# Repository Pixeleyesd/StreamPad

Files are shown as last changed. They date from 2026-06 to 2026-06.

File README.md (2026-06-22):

# StreamPad
The StreamPad is an open source hackpad made for macros (designed for streaming). It has 16 keys (4x4) and an OLED screen.

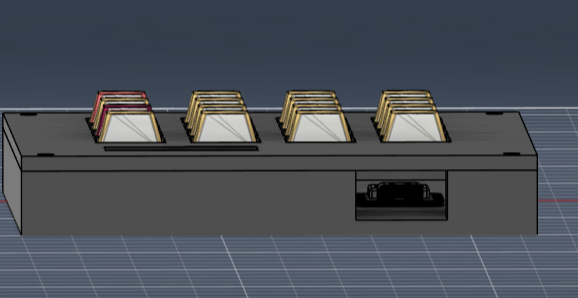
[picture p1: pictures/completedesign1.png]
design1

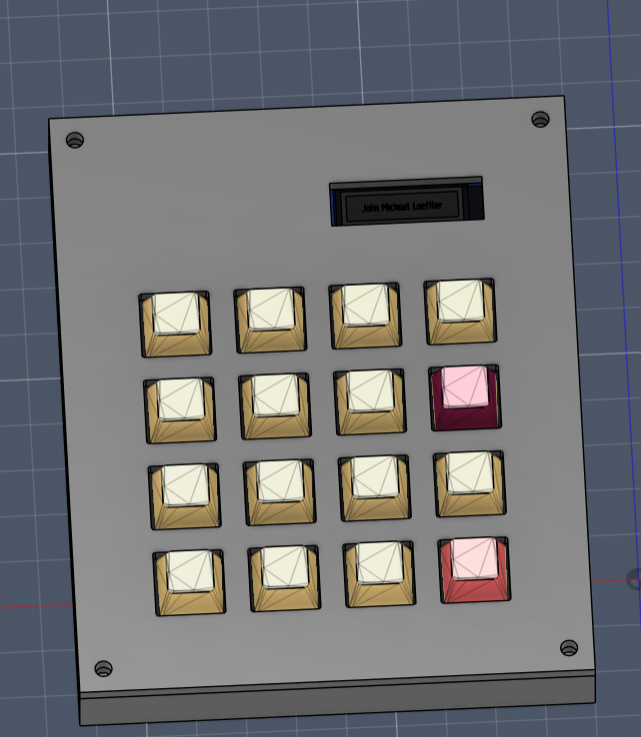
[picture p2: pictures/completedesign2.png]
design2


# PCB
Designed with KiCad.

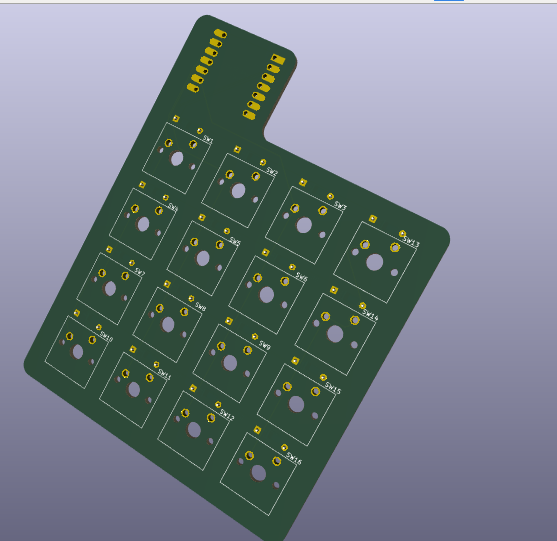
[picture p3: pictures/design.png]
design

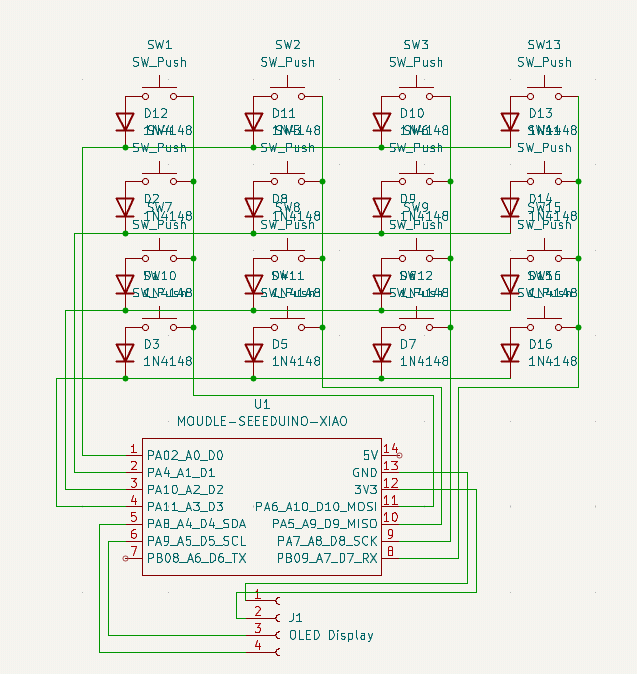
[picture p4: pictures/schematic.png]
schematic

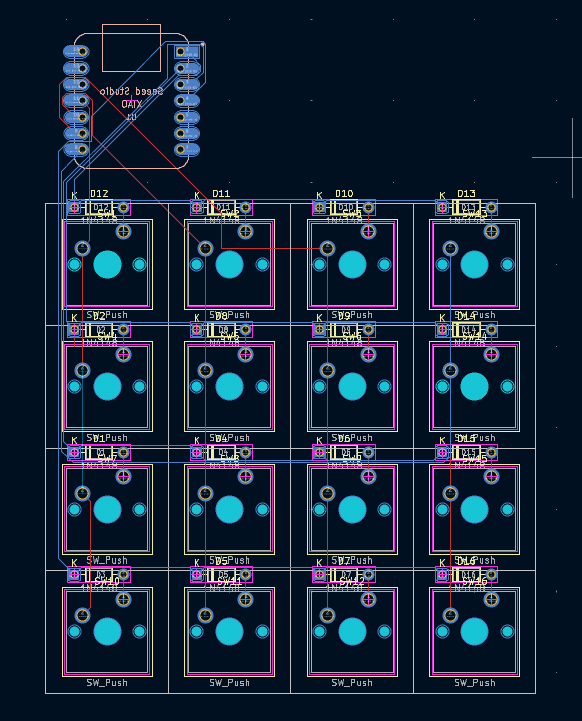
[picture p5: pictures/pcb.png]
pcb


# Case
Designed with fusion 360.

The macropad is assembled by pressing heat-set inserts into the back of the top plate. Then, 16mm screws are inserted through the bottom of the base and the PCB, threading directly into the inserts to hold everything together.

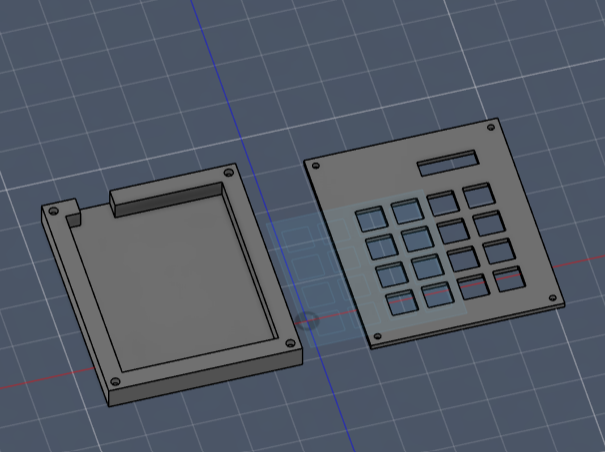
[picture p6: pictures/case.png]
case


# Firmware
The firmware is written in KMK.

You will need to flash the .uf2 provided in the Firmware folder in this repo to the Seeeduino XIAO. (Refer to help here: https://wiki.seeedstudio.com/XIAO-RP2040-with-CircuitPython/)

After this, drag the files in the circuitpy folder provided in this repo into the CIRCUITPY drive that shows up after flashing circuitpython to the microcontroller. Do this as you would a flash drive.

# Assemble
Bill Of Materials (BOM):

1x XIAO RP2040

16x Cherry MX Switches

16x DSA Keycaps

4x M3x5x4 Heatset inserts

4x M3x16mm screws

16x 1N4148 DO-35 Diodes

1x 0.91" 128x32 OLED Display

My 3D printed case (Top & Bottom)

My PCB design. (I'm planning to use JLCPCB for the custom assembly of it)

You will also need to solder wires from XIAO to OLED. The wires will be self-provided: 

GND -> GND

3v3 -> VCC

D4 -> SDA

D5 -> SCL

You will then need to attach the OLED onto the top half of the case.

---

This was my first time ever using KiCad for PCB design, and my first time properly shipping an open source project like this. I learned a lot about this sort of stuff with this project, and made many mistakes I will remember not to make again lol.
Thanks to the Hackclub (and Stardance) team for providing these amazing resources that helped make this dream of mine come true :3

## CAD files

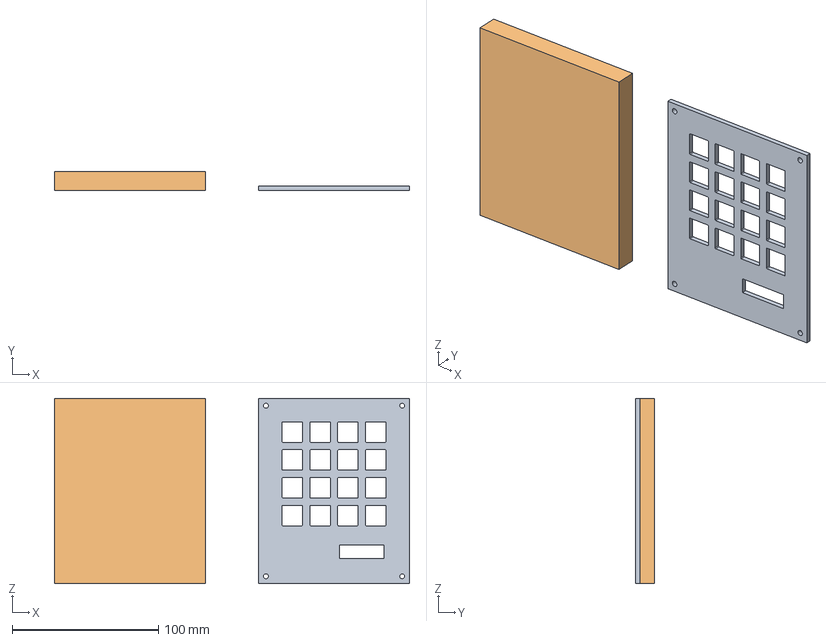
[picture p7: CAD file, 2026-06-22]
CAD/StreamPadCase.step
243.1 x 13.0 x 126.8 mm

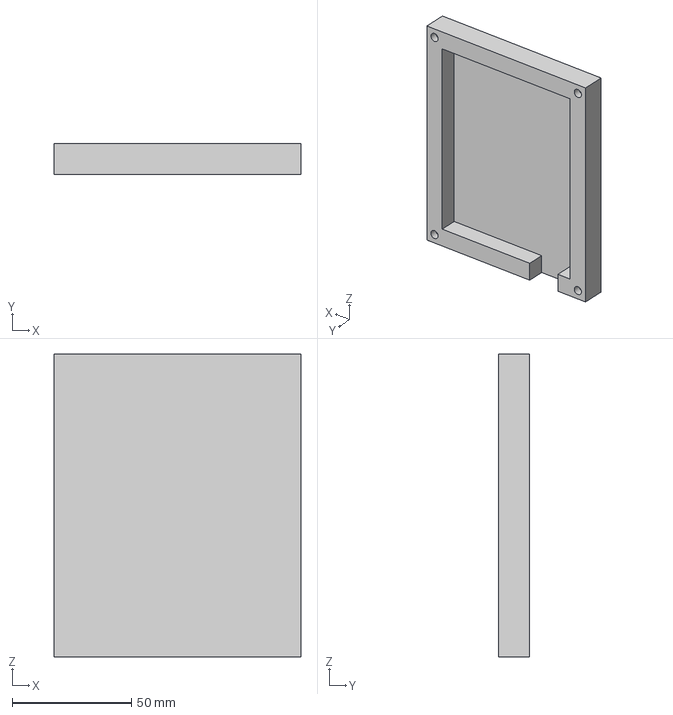
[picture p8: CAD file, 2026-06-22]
production/Bottom.step
103.4 x 13.0 x 126.8 mm

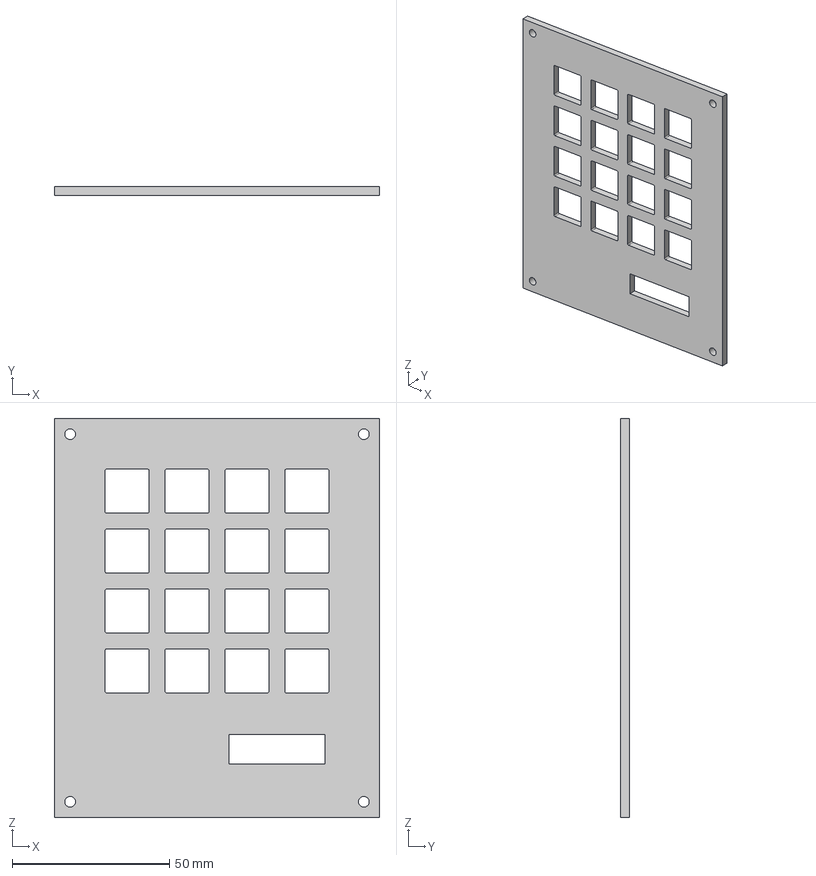
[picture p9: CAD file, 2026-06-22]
production/Top.step
103.4 x 3.00 x 126.8 mm

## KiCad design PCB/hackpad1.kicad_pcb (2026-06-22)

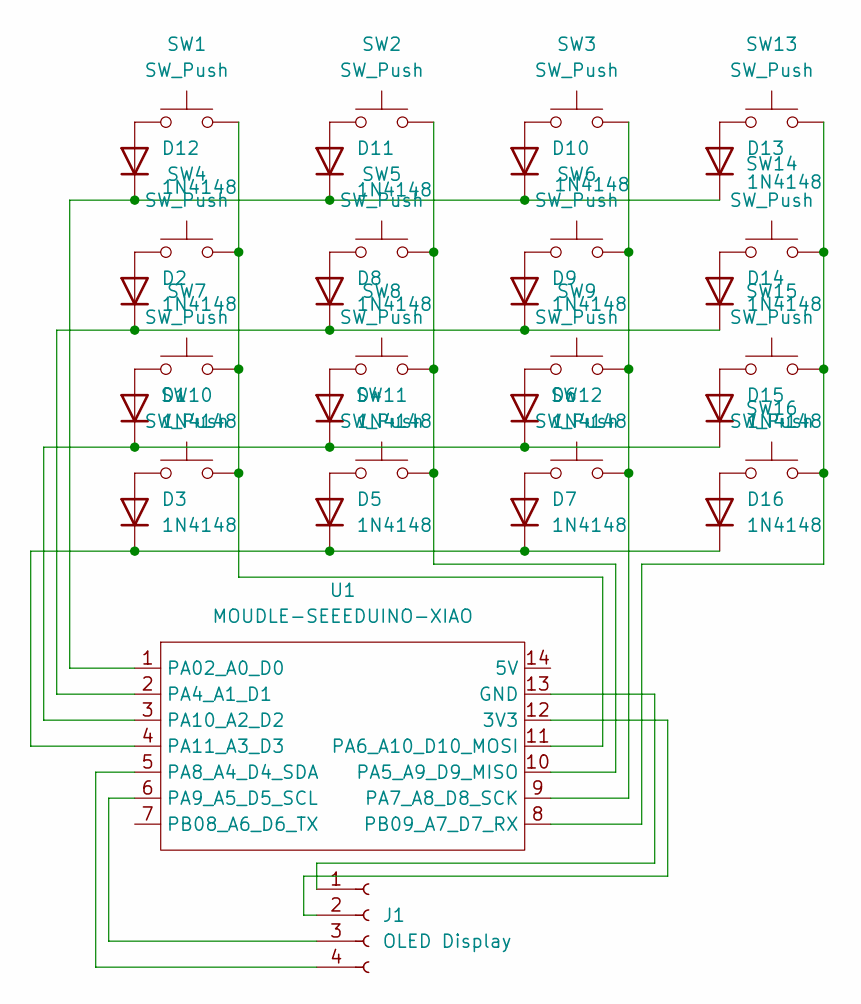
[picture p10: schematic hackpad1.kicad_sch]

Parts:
D1, D2, D3, D4, D5, D6, D7, D8, D9, D10, D11, D12, D13, D14, D15, D16: 1N4148; D_DO-35_SOD27_P7.62mm_Horizontal
J1: OLED Display
SW1, SW2, SW3, SW4, SW5, SW6, SW7, SW8, SW9, SW10, SW11, SW12, SW13, SW14, SW15, SW16: SW_Push; SW_Cherry_MX_1.00u_PCB
U1: MOUDLE-SEEEDUINO-XIAO; XIAO-Generic-Hybrid-14P-2.54-21X17.8MM

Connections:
unnamed: D1.2 (A), SW7.1
unnamed: D1.1 (K), D4.1 (K), D6.1 (K), D15.1 (K), U1.3 (PA10_A2_D2)
unnamed: D2.2 (A), SW4.1
unnamed: D3.2 (A), SW10.1
unnamed: D4.2 (A), SW8.1
unnamed: D5.2 (A), SW11.1
unnamed: D6.2 (A), SW9.1
unnamed: D7.2 (A), SW12.1
unnamed: D8.2 (A), SW5.1
unnamed: D9.2 (A), SW6.1
unnamed: D10.2 (A), SW3.1
unnamed: D10.1 (K), D11.1 (K), D12.1 (K), D13.1 (K), U1.1 (PA02_A0_D0)
unnamed: D11.2 (A), SW2.1
unnamed: D12.2 (A), SW1.1
unnamed: D13.2 (A), SW13.1
unnamed: D14.2 (A), SW14.1
unnamed: D2.1 (K), D8.1 (K), D9.1 (K), D14.1 (K), U1.2 (PA4_A1_D1)
unnamed: D15.2 (A), SW15.1
unnamed: D16.2 (A), SW16.1
unnamed: D3.1 (K), D5.1 (K), D7.1 (K), D16.1 (K), U1.4 (PA11_A3_D3)
unnamed: J1.1, U1.13 (GND)
unnamed: J1.2, U1.12 (3V3)
unnamed: J1.3, U1.6 (PA9_A5_D5_SCL)
unnamed: J1.4, U1.5 (PA8_A4_D4_SDA)
unnamed: SW2.2, SW5.2, SW8.2, SW11.2, U1.10 (PA5_A9_D9_MISO)
unnamed: SW1.2, SW4.2, SW7.2, SW10.2, U1.11 (PA6_A10_D10_MOSI)
unnamed: SW3.2, SW6.2, SW9.2, SW12.2, U1.9 (PA7_A8_D8_SCK)
unnamed: SW13.2, SW14.2, SW15.2, SW16.2, U1.8 (PB09_A7_D7_RX)

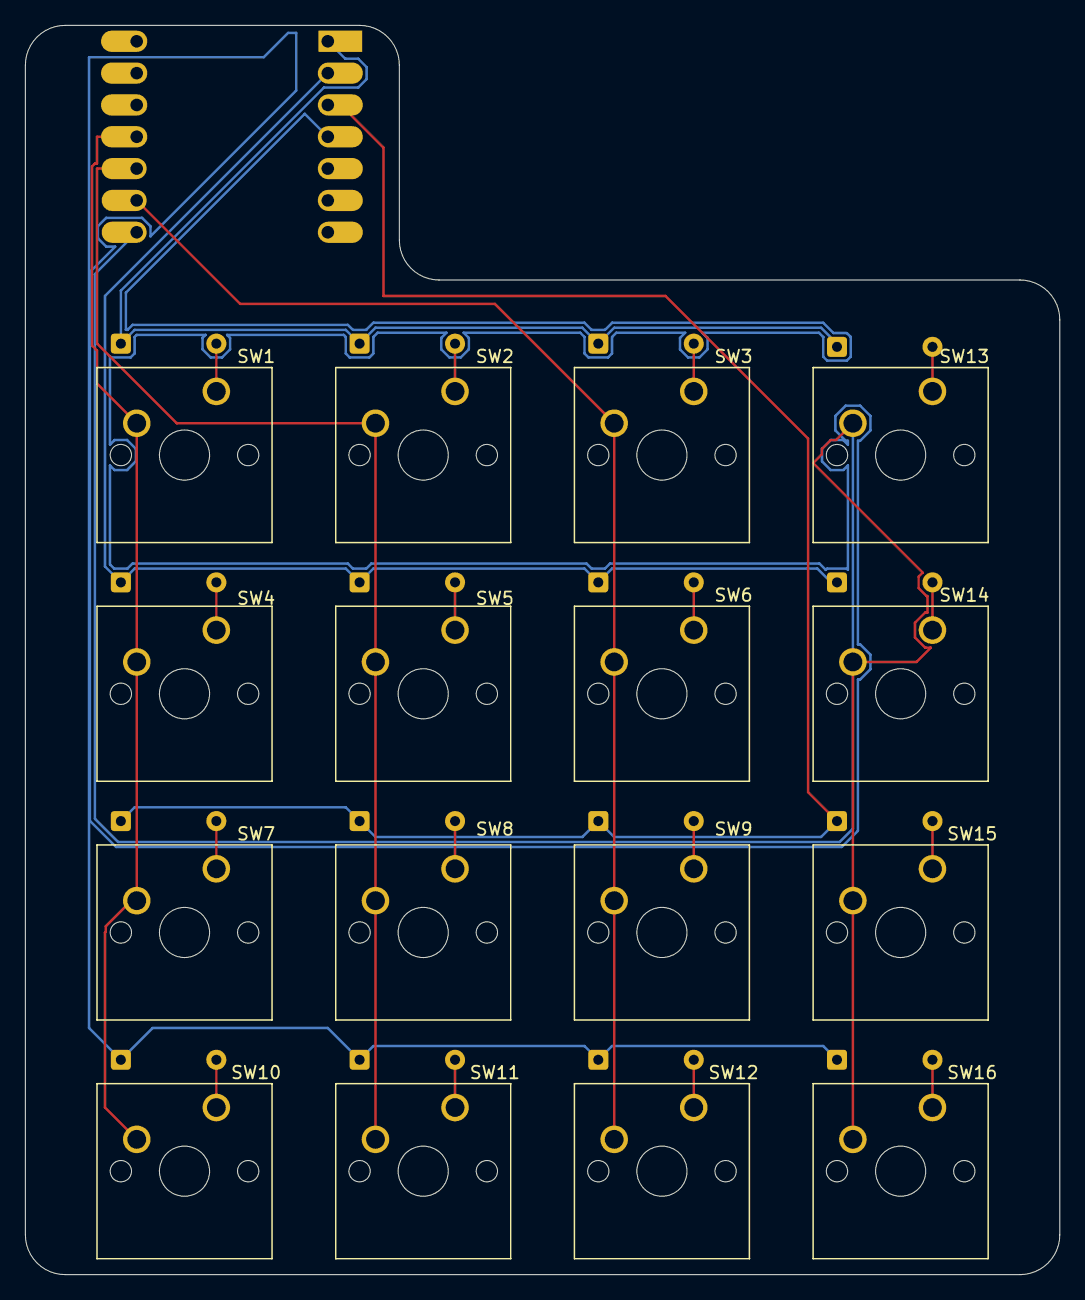
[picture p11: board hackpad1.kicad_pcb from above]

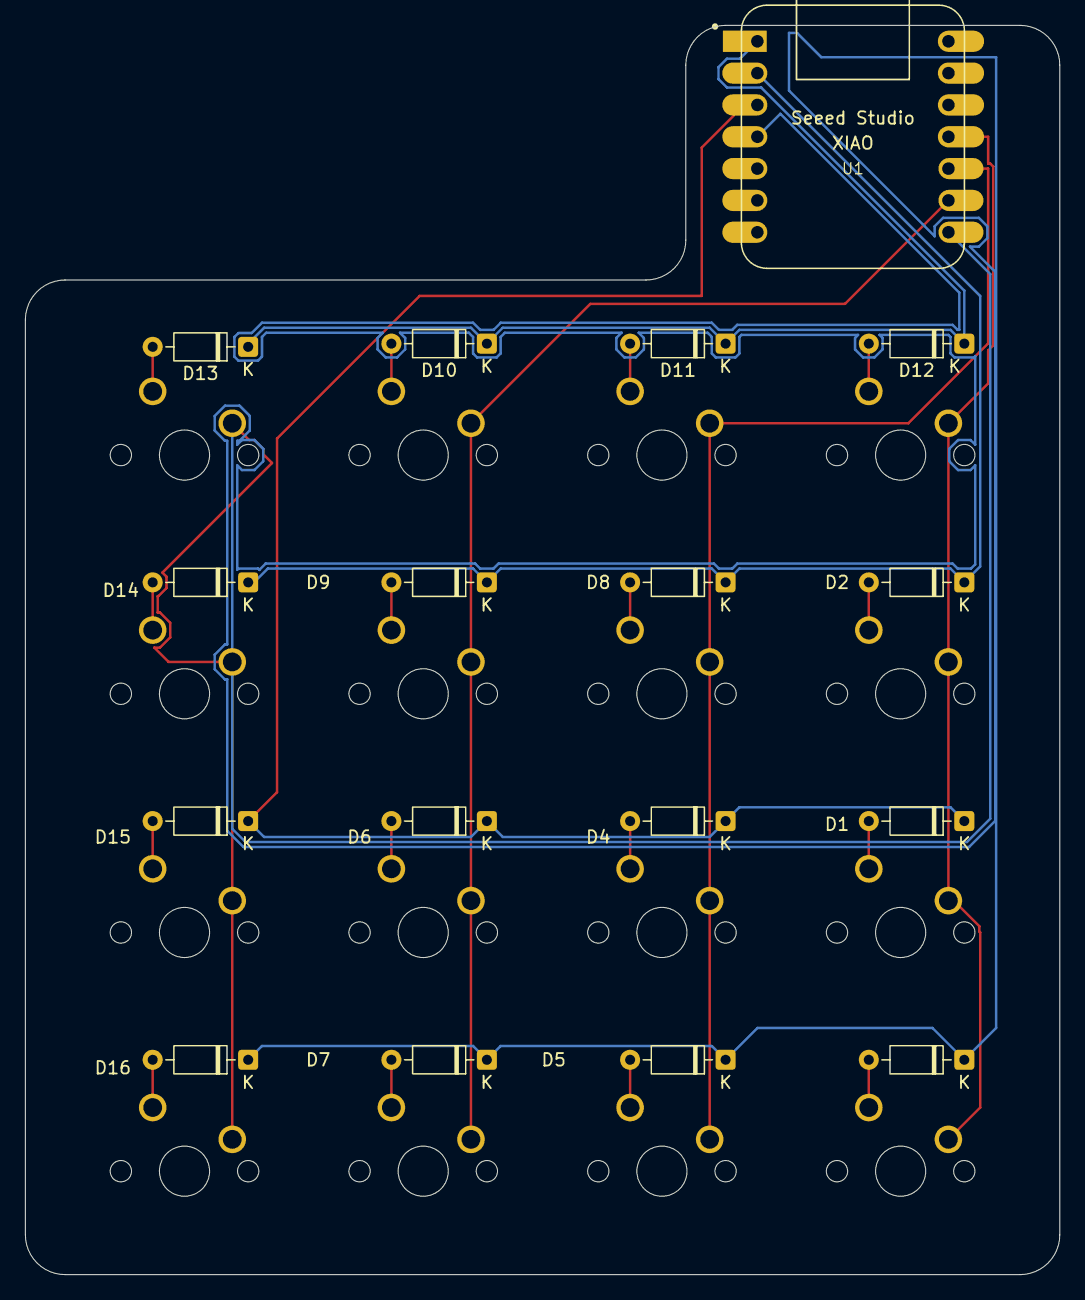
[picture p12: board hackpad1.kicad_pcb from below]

Board: 2 copper layers, 82.5 x 99.7 mm, 33 parts (17 on the bottom side), 24 nets.

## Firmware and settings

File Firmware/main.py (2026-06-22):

import board
import busio
import displayio
import terminalio
import adafruit_displayio_ssd1306
from adafruit_display_text import label
from kmk.kmk_keyboard import KMKKeyboard
from kmk.keys import KC
from kmk.scanners import DiodeOrientation

# oled
displayio.release_displays()
i2c = busio.I2C(board.D5, board.D4)  # scl, sda
display_bus = displayio.I2CDisplay(i2c, device_address=0x3C)
display = adafruit_displayio_ssd1306.SSD1306(display_bus, width=128, height=64)

# splash screen
splash = displayio.Group()

title = label.Label(
    terminalio.FONT,
    text="StreamPad",
    color=0xFFFFFF,
    scale=2,        # big but wont clip (9 chars * 6px * 2 = 108px wide, fits in 128)
    x=10,
    y=10,
)

sub = label.Label(
    terminalio.FONT,
    text="Sub 2 Pixeleyesd",
    color=0xFFFFFF,
    scale=1,        # 17 chars * 6px = 102px wide, fits fine
    x=13,
    y=24,
)

splash.append(title)
splash.append(sub)
display.show(splash)

# keyboard
keyboard = KMKKeyboard()

keyboard.col_pins = (board.D10, board.D9, board.D8, board.D7)
keyboard.row_pins = (board.D0, board.D1, board.D2, board.D3)
keyboard.diode_orientation = DiodeOrientation.COL2ROW

# f13-f24 for rows 1-3, numpad 1-4 for row 4
keyboard.keymap = [
    [
        KC.F13, KC.F14, KC.F15, KC.F16,  # row 1
        KC.F17, KC.F18, KC.F19, KC.F20,  # row 2
        KC.F21, KC.F22, KC.F23, KC.F24,  # row 3
        KC.P1,  KC.P2,  KC.P3,  KC.P4,   # row 4
    ]
]

if __name__ == "__main__":
    keyboard.go()

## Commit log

2026-06-22 Update PCB gluing recommendation in README
    Clarified recommendation for gluing PCB in case.
2026-06-22 Rename 'Build' section to 'Assemble'
2026-06-22 Added StreamPad case files
    Provided in .STEP format to preserve exact geometry.
    [StreamPadBottom.step, StreamPadTop.step]
2026-06-22 Revise PCB design assembly recommendation
    Updated the recommendation for PCB design assembly process.
2026-06-22 Added the gerbers.zip for the PCB
2026-06-22 move StreamPadBottom.step into folder "Print Files"
    [StreamPadBottom.step]
2026-06-22 move StreamPadTop.step into folder "Print Files"
    [StreamPadTop.step]
2026-06-22 move gerbers.zip to folder PCB
2026-06-22 Create directory circuitpy
2026-06-22 add kmk, this time in the circuitpy folder
2026-06-22 Clarify wiring instructions for XIAO to OLED
2026-06-22 Restructured the whole repo for stardance submission
    [Bottom.step, Top.step, hackpad1.kicad_pcb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]
2026-06-22 add full case CAD file
    add full case CAD file (.STEP file format)
    [StreamPadCase.step]
2026-06-22 Revise components list and add assembly notes
    Updated the components list and added notes about the 3D printed case and PCB design.
2026-06-22 updated PCB design to fit requirements for stardance
    [hackpad1.kicad_pcb]
2026-06-22 Added additional PCB image
